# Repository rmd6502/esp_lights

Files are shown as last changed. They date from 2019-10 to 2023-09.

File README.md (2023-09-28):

# esp_lights
Lights driven by ESP8266 and MQTT

# Setup
When first started, the lights will act as an access point, e.g. 'esp8266-lights-livingroom' The password will be whatever you set up in config.h

Select the SSID you want to connect to, enter the password and the IP of the MQTT server, and you should be good to go. You may need to manually reset or power cycle.

# Message
The message sent to the lights is to topic _/lightname/color_ and is a JSON payload, with retention set
_{ color: '#RRGGBB', brightness: 0-1 }_ . You can also leave the brightness at 1 and just change it with the color.

I believe there's also a React webapp included in this repo that will let you change the color of lights from a simple web app.

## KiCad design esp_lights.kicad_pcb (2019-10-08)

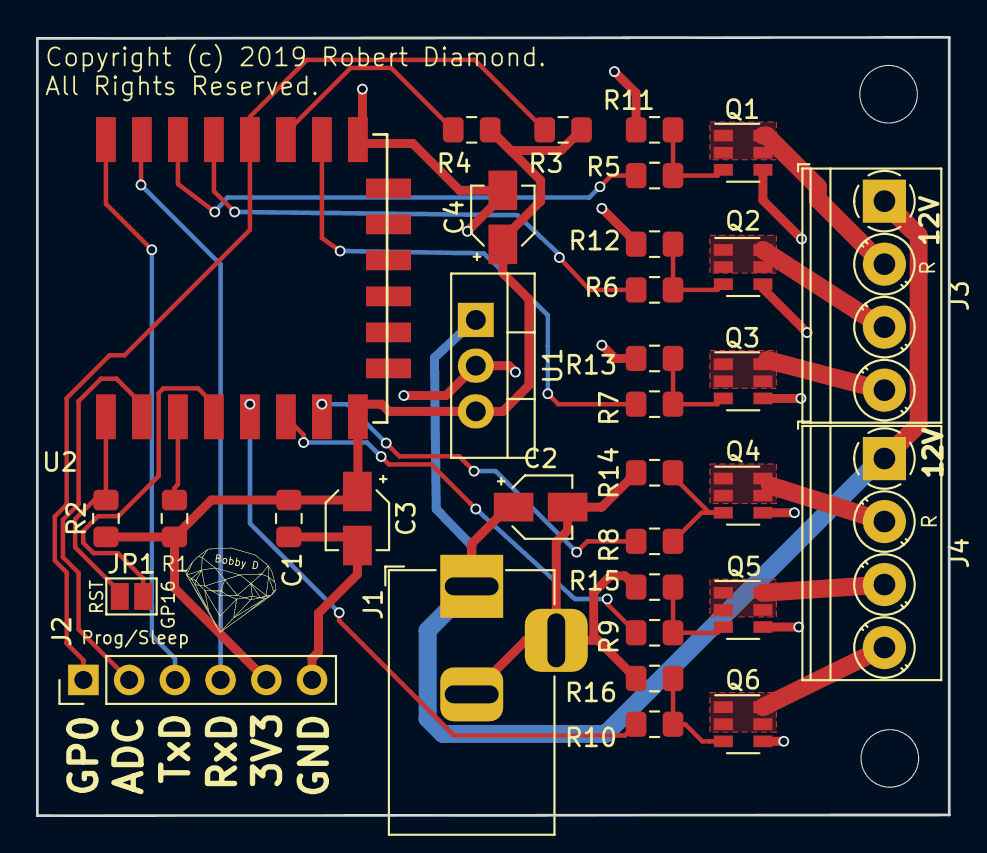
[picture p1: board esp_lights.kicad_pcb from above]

Board: 2 copper layers, 50.7 x 43.2 mm, 33 parts (0 on the bottom side), 29 nets.

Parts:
C1: .1uf; C_0805_2012Metric_Pad1.15x1.40mm_HandSolder
C2: 1uf; CP_Elec_3x5.4
C3: 10uf; CP_Elec_3x5.4
C4: 2.2uf; CP_Elec_3x5.4
J1: Barrel_Jack; BarrelJack_Horizontal
J2: Conn_01x06_Female; PinHeader_1x06_P2.54mm_Vertical
J3, J4: Screw_Terminal_01x04; TerminalBlock_Phoenix_PT-1,5-4-3.5-H_1x04_P3.50mm_Horizontal
JP1: Jumper; SolderJumper-2_P1.3mm_Open_Pad1.0x1.5mm
Q1, Q2, Q3, Q4, Q5, Q6: PMN20EN; SOT-23-6
R1, R2, R3, R4, R11, R12, R13, R14, R15, R16: 10k; R_0805_2012Metric_Pad1.15x1.40mm_HandSolder
R5, R6, R7, R8, R9, R10: 100R; R_0805_2012Metric_Pad1.15x1.40mm_HandSolder
U1: LM7805_TO220; TO-220-3_Vertical
U2: ESP-12Q; ESP-12E_SMD

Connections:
+3V3: C1.1, C3.1, C4.1, J2.5, R1.1, R2.1, R3.1, R4.1, U1.3, U2.8
+12V: C2.1, J1.1, J3.1, J4.1, U1.1
ADC: J2.2, U2.2
Blue1: R7.1, U2.10
Blue2: R10.1, U2.5
GND: C1.2, C2.2, C3.2, C4.2, J1.2, J1.3, J2.6, Q1.4, Q2.4, Q3.4, Q4.4, Q5.4, Q6.4, R11.2, R12.2, R13.2, R14.2, R15.2, R16.2, U1.2, U2.9
GPIO0: J2.1, R3.2, U2.12
GPIO2: R4.2, U2.11
Green1: R6.1, U2.13
Green2: R9.1, U2.6
unnamed: J3.2, Q1.1, Q1.2, Q1.5, Q1.6
unnamed: J3.3, Q2.1, Q2.2, Q2.5, Q2.6
unnamed: J3.4, Q3.1, Q3.2, Q3.5, Q3.6
unnamed: J4.2, Q4.1, Q4.2, Q4.5, Q4.6
unnamed: J4.3, Q5.1, Q5.2, Q5.5, Q5.6
unnamed: J4.4, Q6.1, Q6.2, Q6.5, Q6.6
unnamed: JP1.1, R2.2, U2.1
unnamed: JP1.2, U2.4
unnamed: Q1.3, R5.2, R11.1
unnamed: Q2.3, R6.2, R12.1
unnamed: Q3.3, R7.2, R13.1
unnamed: Q4.3, R8.2, R14.1
unnamed: Q5.3, R9.2, R15.1
unnamed: Q6.3, R10.2, R16.1
unnamed: R1.2, U2.3
Red1: R5.1, U2.14
Red2: R8.1, U2.7
RxD: J2.4, U2.15
TxD: J2.3, U2.16

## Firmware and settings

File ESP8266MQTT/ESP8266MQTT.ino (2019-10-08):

#include <ESP8266WiFi.h>
#include <PubSubClient.h>

#include <ESP8266mDNS.h>

#include <ArduinoJson.h>
#include <ArduinoOTA.h>
#include <WiFiManager.h>

#include "config.h"

// R1,G1,B1,R2,...
uint8_t ledGPIOs[] {5,4,15,13,12,14};

WiFiClient espClient;
PubSubClient client(espClient);
String subscription_key;

void reconnect() {
  // Loop until we're reconnected
  while (!client.connected()) {
    Serial.print("Attempting MQTT connection...");
    // Create a random client ID
    String clientId = "ESP8266Client-";
    clientId += String(random(0xffff), HEX);
    // Attempt to connect
    if (client.connect(clientId.c_str(), mqttUser, mqttPass)) {
      Serial.println("connected");
      // ... and resubscribe
      client.subscribe(subscription_key.c_str());
      return;
    } else {
      Serial.print("failed, rc=");
      Serial.print(client.state());
      Serial.println(" try again in 5 seconds");
      // Wait 5 seconds before retrying
      delay(5000);
    }
  }
}

void callback(char* topic, byte* payload, unsigned int length);
void setup() {
  Serial.begin(115200);
  Serial.println("Starting connecting WiFi.");
  delay(10);
 
  WiFiManager wifiManager;
  wifiManager.setConfigPortalTimeout(180);
  if (!wifiManager.autoConnect(apName, apPass)) {
    Serial.println("failed to connect, we should reset to see if it connects");
    delay(1000);
    ESP.reset();
    delay(5000);
  }
  Serial.println("WiFi connected");
  Serial.println("IP address: ");
  Serial.println(WiFi.localIP());

  client.setServer(mqttHost, 1883);
  client.setCallback(callback);
  subscription_key = mqttUser;
  subscription_key += "/feeds";
  subscription_key += subscription;
  Serial.println(subscription_key);
 
   ArduinoOTA.setHostname(host);

   ArduinoOTA
    .onStart([]() {
      String type;
      if (ArduinoOTA.getCommand() == U_FLASH)
        type = "sketch";
      else // U_SPIFFS
        type = "filesystem";

      // NOTE: if updating SPIFFS this would be the place to unmount SPIFFS using SPIFFS.end()
      Serial.println("Start updating " + type);
    });
    ArduinoOTA.onEnd([]() {
      Serial.println("\nEnd");
    });
    ArduinoOTA.onProgress([](unsigned int progress, unsigned int total) {
      Serial.printf("Progress: %u%%\r", (progress / (total / 100)));
    });
    ArduinoOTA.onError([](ota_error_t error) {
      Serial.printf("Error[%u]: ", error);
      if (error == OTA_AUTH_ERROR) Serial.println("Auth Failed");
      else if (error == OTA_BEGIN_ERROR) Serial.println("Begin Failed");
      else if (error == OTA_CONNECT_ERROR) Serial.println("Connect Failed");
      else if (error == OTA_RECEIVE_ERROR) Serial.println("Receive Failed");
      else if (error == OTA_END_ERROR) Serial.println("End Failed");
    });
    ArduinoOTA.begin();

    analogWriteFreq(8000);
    analogWriteRange(255);
}

void loop() {
  ArduinoOTA.handle();
  client.loop();

  if (!client.connected()) {
    reconnect();
  }
}

void setLEDColor(const char *colorstr);
void callback(char* topic, byte* payload, unsigned int length) {
  Serial.print("Message arrived [");
  Serial.print(topic);
  Serial.print("] ");
  for (int i = 0; i < length; i++) {
    Serial.print((char)payload[i]);
  }
  Serial.println();
  char *payloadStr = (char *)malloc(length + 1);
  strncpy(payloadStr, (char *)payload, length);
  payloadStr[length] = '\0';
  setLEDColor(payloadStr);
  free(payloadStr);
}
/* colorstr = RRGGBB in hex */
 void setLEDColor(const char *colorstr) {
  uint32_t r,g,b;
  if (colorstr[0] == '#') {
    sscanf(colorstr, "#%02x%02x%02x", &r, &g, &b);
  } else {
    sscanf(colorstr, "%ld", &r);
    g=b=0;
  }
  
  Serial.printf("SetLED R %d G %d B %d", r, g, b);
  analogWrite(ledGPIOs[0], r);
  analogWrite(ledGPIOs[3], r);
  analogWrite(ledGPIOs[1], g);
  analogWrite(ledGPIOs[4], g);
  analogWrite(ledGPIOs[2], b);
  analogWrite(ledGPIOs[5], b);
}

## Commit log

2019-10-06 initial copy back to git
    [esp_lights.kicad_pcb, esp_lights.sch]
2019-10-06 add more files
    [esp_lights-B_Cu.gbr, esp_lights-B_Mask.gbr, esp_lights-B_SilkS.gbr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]
2019-10-08 add firmware
    [esp_lights.kicad_pcb, esp_lights.sch]
2023-01-23 add mqtt control
    [esp_lights-B_Cu.gbr, esp_lights-B_Mask.gbr, esp_lights-B_SilkS.gbr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]

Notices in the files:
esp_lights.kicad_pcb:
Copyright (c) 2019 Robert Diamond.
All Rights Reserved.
